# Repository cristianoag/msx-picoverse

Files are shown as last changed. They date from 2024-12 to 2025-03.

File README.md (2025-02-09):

# MSX PicoVerse - The MSX experience driven by the RaspBerry Pi Pico

The MSX PicoVerse is an open-source initiative aimed at developing multi-function cartridges for the MSX line of computers, utilizing variations of the Raspberry Pi Pico development boards with the RP2040 and RP2350 integrated chips. 

This project aspires to enhance the MSX experience by enabling users to load ROMs, emulate hardware, connect to wireless networks, or even create new hardware through a software-defined approach.

The project is still in development, and we are looking for contributors to help us develop the hardware and software. If you are interested in contributing, please reach out.

> **Note:** At this moment there is no guarantee that the boards and or software will work as expected. This project is still a work in progress. If you decide to build the hardware, you do so at your own risk.

## Hardware

Hardware was designed in two classes, first covering the RP2040 chip variants and the second covering the RP2350B chip variants. The designs are based on the Raspberry Pico development boards, which are widely available and have a large community of developers.

### Cartridges based on the RP2040 chip (PicoVerse 2040)

The RP2040 is a dual-core ARM Cortex-M0+ microcontroller operating initially at 133 MHz, featuring 264 KB of SRAM and support for external flash memory. It offers a variety of interfaces, including GPIO pins, SPI, I²C, UART, ADCs, PWM channels, and USB support.

| Prototype PCB (front) | Prototype PCB (back) |
|---|---|
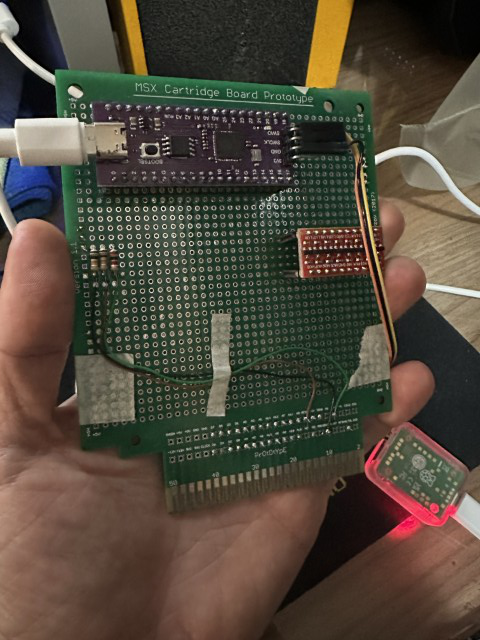
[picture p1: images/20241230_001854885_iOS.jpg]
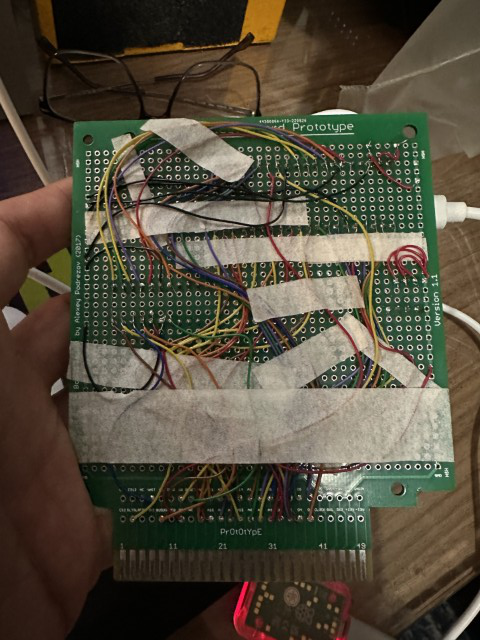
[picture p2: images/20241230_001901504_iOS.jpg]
|  |  | 

PicoVerse 2040 cartridges are designed for development boards that expose 30 GPIO pins and are **NOT compatible** with standard Raspberry Pi Pico boards. 

The goal was to use only the GPIO pins available on the boards and avoid the use of IO pin expanders or other components that could increase the complexity of the design. 

#### PicoVerse 2040 MultiRom Cartridge

The PicoVerse 2040 MultiRom allows usets to load multiple ROMs into the cartridge and select which one to boot the MSX. The cartridge has a USB port that can be used to connect it to a PC with Windows or Linux and transfer the ROMs to the Pico flash memory.

A few boards were designed for the PicoVerse 2040 MultiRom Cartridge. Most of them have the GPIO pins connected to the MSX bus through level shifters. The level shifters are used to convert the 3.3V signals from the Pico board to 5V signals that are used by the MSX bus. 

One of the boards was designed to have the majority of the GPIO pins connected directly to the MSX bus without level shifters. There is a debate about the safety of connecting the Pico GPIOs directly to 5V, as it can damage the board as it is not officially documented that the GPIO pins can be connected directly to 5V. So use the board with the level shifters if you are concerned about that. 

The boards highlighted below have the same features, the only difference is the presence of level shifters in the first one. They both use the Purple RP2040 board that is available on AliExpress and exposes 30 GPIOs.

|Cartridge Design Files|BOM|Image|
|---|---|---|
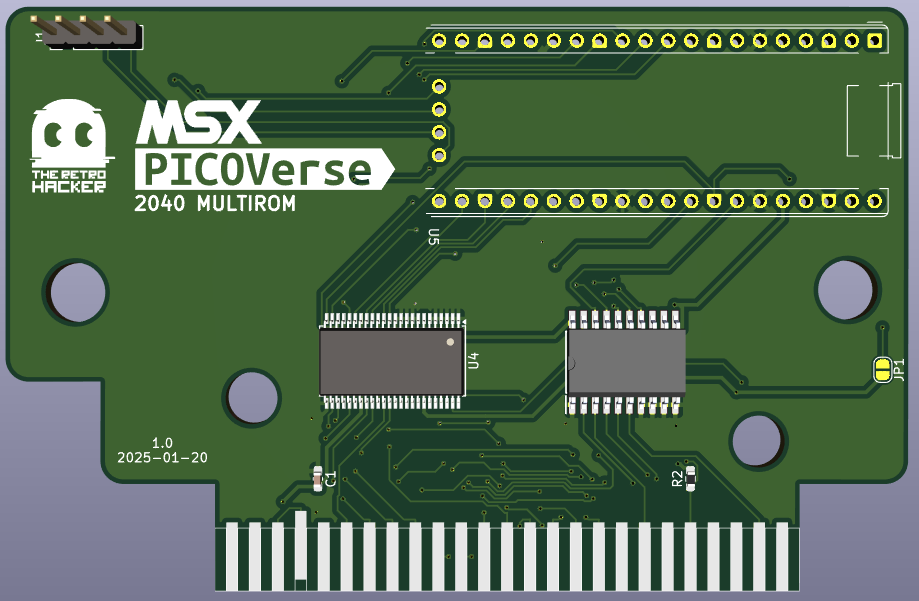
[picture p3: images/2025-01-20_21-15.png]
|[PicoVerse 2040 MultiRom](multirom/hardware/ALIEXPRESS-RP2040-PURPLE/1.0)|[BOM](https://htmlpreview.github.io/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)||
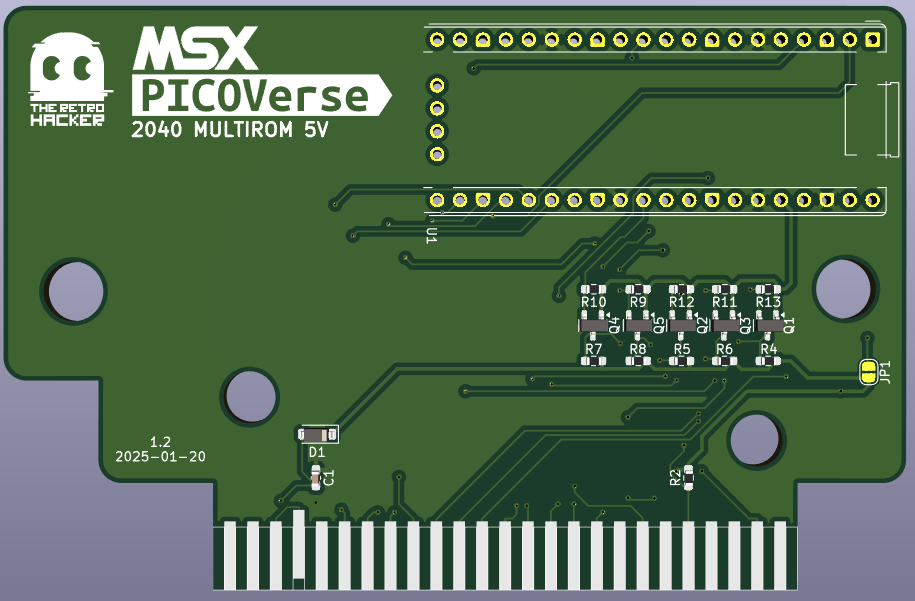
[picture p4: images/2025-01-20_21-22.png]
|[PicoVerse 2040 MultiRom 5V](multirom/hardware/ALIEXPRESS-RP2040-PURPLE-5V/1.2)|[BOM](https://htmlpreview.github.io/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)||

#### PicoVerse 2040 Audio Cartridge

The PicoVerse 2040 Audio Cartridge is a cartridge that allows the user to play MP3 audio files on the MSX computer and implements audio related resources to be used by software running on the MSX computer. The cartridge has a USB port that can be used to connect the cartridge to a computer and transfer simple (up to 48KB) ROMs or music files to the Pico flash memory. 

At this moment the cartridge features a MP3 player client for the MSX computer that can be used to play music files stored on the Pico flash memory.

|Cartridge Design Files|BOM|Image|
|---|---|---|
|TBI|||

#### PicoVerse 2040 WiFi Cartridge

The PicoVerse 2040 WiFi Cartridge is a cartridge that allows the user to connect the MSX computer to a wireless network. The cartridge has a USB port that can be used to connect the cartridge to a computer and update the firmware.

The cartridge features a UNAPI driver for the MSX computer that can be used to connect to a wireless network. The driver was created by Oduvaldo Pavan Jr. and is available on his [GitHub repository](https://github.com/ducasp/MSX-Development).

|Cartridge Design Files|BOM|Image|
|---|---|---|
|TBI|||

### Cartridges based on the RP2350B chip (PicoVerse 2350)

The RP2350, introduced in August 2024 by Raspberry Pi Ltd., is a high-performance microcontroller featuring a dual-core, dual-architecture design with selectable Arm Cortex-M33 or Hazard3 RISC-V cores, operating up to 150 MHz. It includes 520 KB of on-chip SRAM, supports up to 16 MB of external QSPI flash or PSRAM, and offers multiple communication interfaces (2× UART, 2× SPI, 2× I²C), 24 PWM channels, up to 8 ADC channels, 48 GPIO pins, USB 1.1 support, and 12 PIO state machines for flexible interfacing.

| Prototype PCB (front) | Prototype PCB (back) |
|---|---|
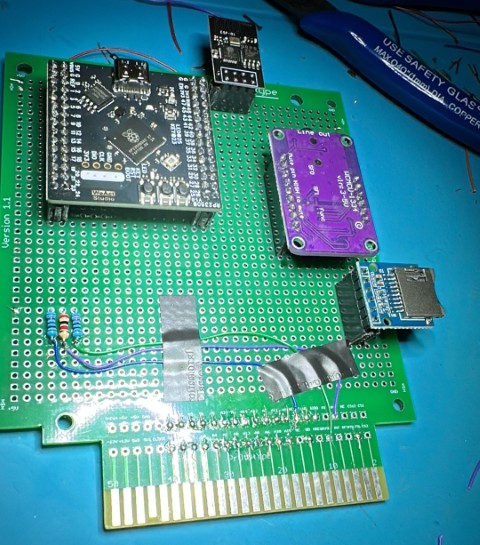
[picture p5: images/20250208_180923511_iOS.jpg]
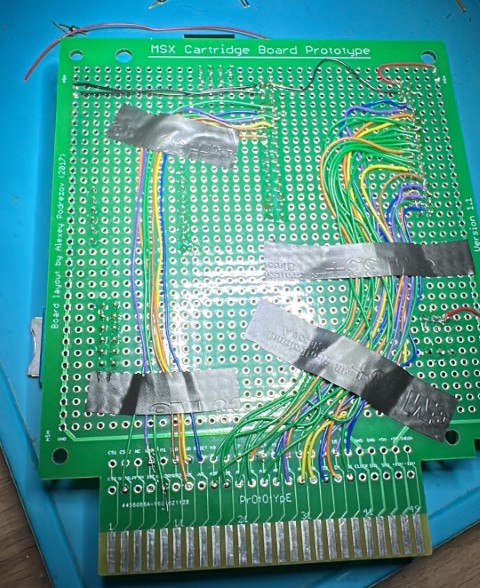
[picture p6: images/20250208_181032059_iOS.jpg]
|  |  |

PicoVerse 2350 cartridges are based on development boards that expose 48 GPIO pins and are **NOT compatible** with conventional Raspberry Pi Pico 2 development boards, which typically expose only 26 GPIO pins. 

#### PicoVerse 2350 Multirom Cartridge

This is a combined cartridge that includes the features of the PicoVerse 2040 MultiRom, Audio, and WiFi cartridges. The cartridge has a USB port that can be used to connect the cartridge to a computer and transfer ROM or music files to the Pico flash memory.

|Cartridge Design Files|BOM|Image|
|---|---|---|
|TBI|||

## Software

The software for the PicoVerse cartridges is being developed and it will be fully open-sourced. 

The RP2040 based carts are also compatible with the [MSX&#960;](https://github.com/piigaa-densetu-two-dai/MSXpi) project created by @piigaa-densetu-two-dai, so you can use any of the software alternatives created for that board with this open source hardware.

#### PicoVerse 2040 MultiRom Cartridge

As this was the first cartridge to be developed, there are a few software options available. You can check options with descriptions and download links in the [software](2040/multirom/software) folder.

The PicoVerse 2040 MultiRom Cartridge is also compatible with the [MSX&#960;](https://github.com/piigaa-densetu-two-dai/MSXpi) project created by @piigaa-densetu-two-dai, so you can use any of the software alternatives created for that board with this open source hardware.

#### PicoVerse 2040 Audio Cartridge

The software for the PicoVerse 2040 Audio Cartridge is being developed. The software will be fully open-sourced.

#### PicoVerse 2040 WiFi Cartridge

The software for the PicoVerse 2040 WiFi Cartridge is being developed. The software will be fully open-sourced.

#### PicoVerse 2350 Multirom Cartridge

The software for the PicoVerse 2350 Multirom Cartridge is being developed. You can check options with descriptions and download links in the [software](2350/multirom/software) folder.

## License 

Open Hardware

This work is licensed under a [Creative Commons Attribution-NonCommercial-ShareAlike 4.0 International License](http://creativecommons.org/licenses/by-nc-sa/4.0/).

* If you remix, transform, or build upon the material, you must distribute your contributions under the same license as the original.
* You may not use the material for commercial purposes.
* You must give appropriate credit, provide a link to the license, and indicate if changes were made. You may do so in any reasonable manner, but not in any way that suggests the licensor endorses you or your use.

**ATTENTION**

This project was made for the retro community and not for commercial purposes. So only retro hardware forums and individual people can build this project.

THE SALE OF ANY PART OF THIS PROJECT WITHOUT EXPRESS AUTHORIZATION IS PROHIBITED!

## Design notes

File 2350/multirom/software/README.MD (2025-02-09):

# MSX PICOVERSE 2350 MULTIROM SOFTWARE PLAYGROUND

This page summarizes the software options currently available or in development for the PicoVerse 2350 MultiRom cartridge. 

## Software and Tools you may need to develop for the PicoVerse 2350

* [Visual Studio Code]( https://code.visualstudio.com/) - Code editor that can be used to develop software for the PicoVerse 2040 cartridges.
* [Raspberry Pi Pico SDK](https://github.com/raspberrypi/pico-sdk) - The SDK is a collection of libraries and tools that are designed to make it easy to write programs for the RP2040 microcontroller.  
* [SDCC](http://sdcc.sourceforge.net/) - Small Device C Compiler. Standard C (ANSI C89, ISO C99, ISO C11) compiler that targets the Zilog Z80 based microcontrollers (z80, z180, gbz80, Rabbit 2000/3000, Rabbit 3000A, TLCS-90) for cross-development on Windows, macOS, and Linux. 
* [Fusion-C v1.3](https://github.com/ericb59/FUSION-C-1.3) - Fusion-C is a set of development tools for the MSX system that allows you to write MSX software in C language.
* [MYSYS2](https://www.msys2.org/) - A collection of GNU utilities and open-source software that provides functionality similar to a Linux distribution on Windows. If you are using Windows to develop for the cartridge.
* [GNU Make](https://www.gnu.org/software/make/) - A tool that controls the generation of executables and other non-source files of a program from the program's source files.
* [uf2conv.exe](https://github.com/microsoft/uf2/) - Converts a binary file to a UF2 file. This is used to convert resultant binary files to a UF2 file that can be flashed to the PICO board. 

## Software

### [loadrom](loadrom/)

This is a firmware to load a single ROM image (up to 10MB) from the flash memory of the PICO 2350 board. The ROM image is read directly from the flash memory and then executed. At this moment the tool can load and execute ROMs of the following types:

* Plain16  
* Plain32  
* Linear0  
* Konami SCC  
* Konami (without SCC)  
* ASCII8  
* ASCII16 
* NEO-8 
* NEO-16

To use you need to run loadrom.exe passing the ROM file as a parameter. The tool will read the ROM file, detect the mapper used using a heuristic approach, and then create a UF2 file that can be used to program the PICO board. 
```
loadrom.exe romfile.rom
```
After the tool execution, you need to connect your cartridge to the PC via the USB-C cable with the BOOTSEL button pushed, and copy the loadrom.uf2 file to drive that will be created in your operating system. The ROM will be loaded and executed on the MSX when the cartridge is inserted to the slot.

### [multirom](multirom/)

This is an alternative firmware that allows the selection of a ROM image from a list of ROMs stored in the flash memory of the PICO 2350 board. The ROM image is read directly from the Raspberry Pi Pico flash memory and executed on the MSX. 

At this moment the tool can load and execute following ROM types:

* Plain16  
* Plain32  
* Linear0  
* Konami SCC  
* Konami (without SCC)  
* ASCII8  
* ASCII16  
* NEO-8 
* NEO-16
  
To use it you need to run the multirom.exe tool in the same folder as the ROM files. Please rename the ROM files with names with up to 20 characters in the way you want them to appear in the menu. The tool will read the ROM files, detect their type and create a UF2 file that can be used to program the PICO board. 

```
multirom.exe
```
Then connect your cartridge to the PC via the USB-C cable and copy the multirom.uf2 file to the PICO board. The menu will be executed and you can select the ROM to be loaded to the MSX.

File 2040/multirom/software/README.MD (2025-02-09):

# MSX PICOVERSE 2040 MULTIROM SOFTWARE PLAYGROUND

This page summarizes the software options currently available or in development for the PicoVerse 2040 MultiRom cartridge. 

## Software and Tools you may need to develop for the PicoVerse 2040

* [Visual Studio Code]( https://code.visualstudio.com/) - Code editor that can be used to develop software for the PicoVerse 2040 cartridges.
* [Raspberry Pi Pico SDK](https://github.com/raspberrypi/pico-sdk) - The SDK is a collection of libraries and tools that are designed to make it easy to write programs for the RP2040 microcontroller.  
* [SDCC](http://sdcc.sourceforge.net/) - Small Device C Compiler. Standard C (ANSI C89, ISO C99, ISO C11) compiler that targets the Zilog Z80 based microcontrollers (z80, z180, gbz80, Rabbit 2000/3000, Rabbit 3000A, TLCS-90) for cross-development on Windows, macOS, and Linux. 
* [Fusion-C v1.3](https://github.com/ericb59/FUSION-C-1.3) - Fusion-C is a set of development tools for the MSX system that allows you to write MSX software in C language.
* [MYSYS2](https://www.msys2.org/) - A collection of GNU utilities and open-source software that provides functionality similar to a Linux distribution on Windows. If you are using Windows to develop for the cartridge.
* [GNU Make](https://www.gnu.org/software/make/) - A tool that controls the generation of executables and other non-source files of a program from the program's source files.
* [uf2conv.exe](https://github.com/microsoft/uf2/) - Converts a binary file to a UF2 file. This is used to convert resultant binary files to a UF2 file that can be flashed to the PICO board. 

## Software

### [testflash1](testflash1/)

This is small test program that demonstrates how to read the content of a ROM image that is appended to the end of the main program in the PICO flash memory. The ROM data is read from the flash memory and dumped to the serial console in hexdump format.

To use it you need to concatenate the ROM to the resultant bin file for the testflash1. Use the following commands to prepare the UF2 file:

```
copy /b testflash1.bin+romfile.rom testflash1-rom.bin
uf2conv.exe testflash1-rom.bin testflash1-rom.uf2
```

### [loadrom](loadrom/dist/)

This is a firmware to load a single ROM image (up to 10MB) from the flash memory of the PICO board. The ROM image is read directly from the flash memory and then executed. At this moment the tool can load and execute ROMs of the following types:

* Plain16  
* Plain32  
* Linear0  
* Konami SCC  
* Konami (without SCC)  
* ASCII8  
* ASCII16 
* NEO-8 
* NEO-16

To use you need to run loadrom.exe passing the ROM file as a parameter. The tool will read the ROM file, detect the mapper used using a heuristic approach, and then create a UF2 file that can be used to program the PICO board. 
```
loadrom.exe romfile.rom
```
After the tool execution, you need to connect your cartridge to the PC via the USB-C cable with the BOOTSEL button pushed, and copy the loadrom.uf2 file to drive that will be created in your operating system. The ROM will be loaded and executed on the MSX when the cartridge is inserted to the slot.

### [multirom](multirom/)

This is an alternative firmware that allows the selection of a ROM image from a list of ROMs stored in the flash memory of the PICO board. The ROM image is read directly from the Raspberry Pi Pico flash memory and executed on the MSX. 

|Menu - Page1|Menu - Page2|
|---|---|
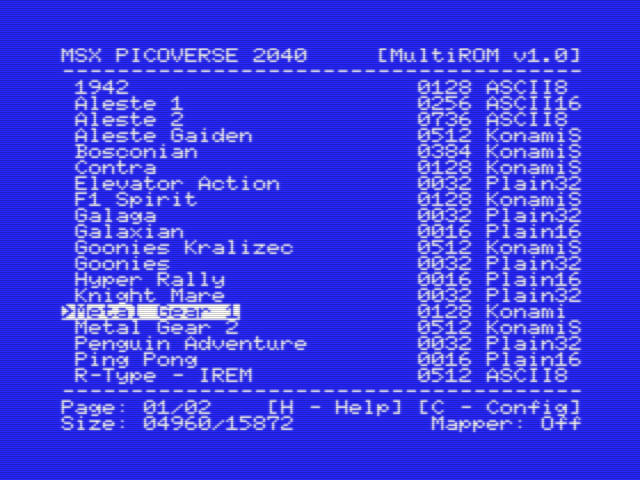
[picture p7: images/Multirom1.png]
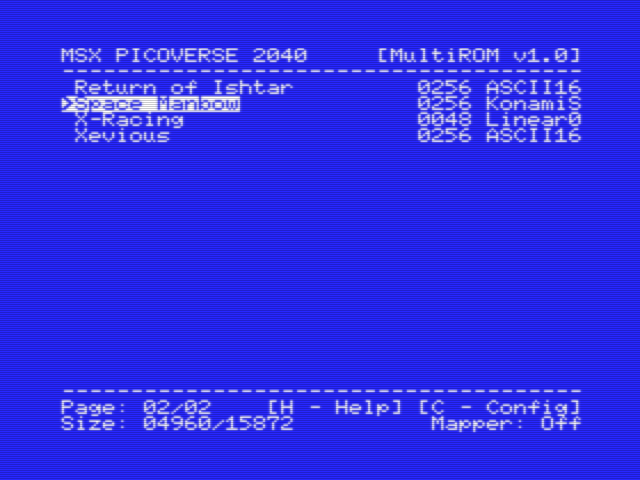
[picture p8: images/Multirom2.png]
|||

At this moment the tool can load and execute following ROM types:

* Plain16  
* Plain32  
* Linear0  
* Konami SCC  
* Konami (without SCC)  
* ASCII8  
* ASCII16  
* NEO-8 
* NEO-16
  
To use it you need to run the multirom.exe tool in the same folder as the ROM files. Please rename the ROM files with names with up to 20 characters in the way you want them to appear in the menu. The tool will read the ROM files, detect their type and create a UF2 file that can be used to program the PICO board. 

```
multirom.exe
```
Then connect your cartridge to the PC via the USB-C cable and copy the multirom.uf2 file to the PICO board. The menu will be executed and you can select the ROM to be loaded to the MSX.

### [mmapper](mmapper/)

The mmapper firmwate implements a 128KB memory mapper on the MSX computer. You just need to compile the code and copy the UF2 file to the PICO board. The firmware will be loaded and the memory mapper will be available to the MSX computer.

### [flashrom](flashrom/)

The Flashrom firmware allows loading ROMs from the Raspberry Pi Pico's flash memory. When you flash the cartridge with this firmware, a new drive will be created/appear on your PC when you connect the cartridge/pico to it via USB cable. The drive has the name PICOVERSE.

You can then push and hold the BOOTSEL button on the cartridge to format the drive and then drag and drop ROM files to it. The cartridge will then read the ROM files and make them available to the MSX computer user via a menu system. The user can then select the ROM to be loaded into the MSX computer.

* FatFS - http://elm-chan.org/fsw/ff/
* PicoUSB Flash Drive - https://github.com/oyama/pico-usb-flash-drive
* SPIFTL - Embedded, Static Wear-Leveling FTL Library - https://github.com/earlephilhower/SPIFTL

```
In development
```

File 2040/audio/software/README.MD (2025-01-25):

# MSX PICOVERSE 2040 AUDIO SOFTWARE PLAYGROUND

This page summarizes the software options currently available or in development for the PicoVerse 2040 Audio cartridge. 

## Software and Tools you may need to develop for the PicoVerse 2040

* [Visual Studio Code]( https://code.visualstudio.com/) - Code editor that can be used to develop software for the PicoVerse 2040 cartridges.
* [Raspberry Pi Pico SDK](https://github.com/raspberrypi/pico-sdk) - The SDK is a collection of libraries and tools that are designed to make it easy to write programs for the RP2040 microcontroller.  
* [SDCC](http://sdcc.sourceforge.net/) - Small Device C Compiler. Standard C (ANSI C89, ISO C99, ISO C11) compiler that targets the Zilog Z80 based microcontrollers (z80, z180, gbz80, Rabbit 2000/3000, Rabbit 3000A, TLCS-90) for cross-development on Windows, macOS, and Linux. 
* [Fusion-C v1.3](https://github.com/ericb59/FUSION-C-1.3) - Fusion-C is a set of development tools for the MSX system that allows you to write MSX software in C language.
* [MYSYS2](https://www.msys2.org/) - A collection of GNU utilities and open-source software that provides functionality similar to a Linux distribution on Windows. If you are using Windows to develop for the cartridge.
* [GNU Make](https://www.gnu.org/software/make/) - A tool that controls the generation of executables and other non-source files of a program from the program's source files.
* [uf2conv.exe](https://github.com/microsoft/uf2/) - Converts a binary file to a UF2 file. This is used to convert resultant binary files to a UF2 file that can be flashed to the PICO board. 

## Software

### [loadmp3](loadmp3/)

Loadmp3 is a simple utility that converts MP3 files to a format that can be played by the PicoVerse 2040 Audio cartridge. The utility converts MP3 files to a format that can be played by the UDA1334A I2S Stereo DAC. 

```
loadmp3 <filename>
```
After the tool execution, you need to connect your cartridge to the PC via the USB-C cable with the BOOTSEL button pushed, and copy the loadrom.uf2 file to drive that will be created in your operating system. The MP3 file will be played on your MSX computer. 

### [musicplayer](musicplayer/)

This is a simple music player that plays music files stored in the flash memory of the PICO board. The music files are stored in the flash memory and are played using the UDA1334A I2S Stereo DAC. The music player supports the following file formats:

* MP3

In development!

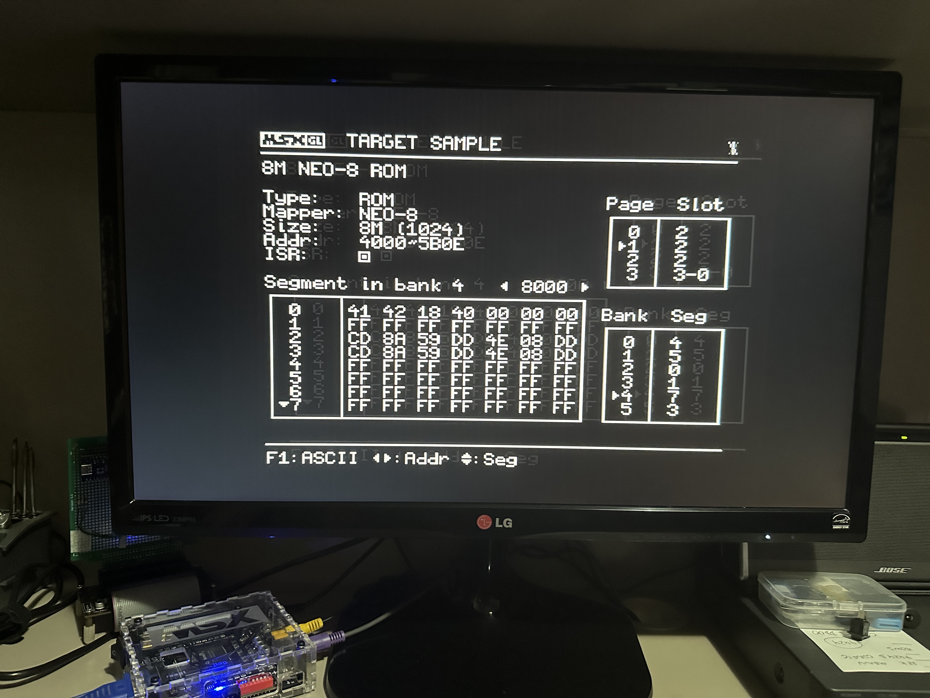
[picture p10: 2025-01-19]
images/20250119_003103586_iOS.jpg

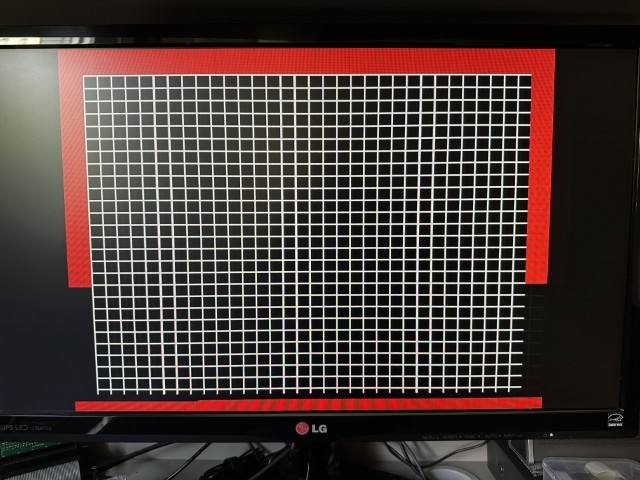
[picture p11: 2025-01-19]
images/20250119_131752036_iOS.jpg

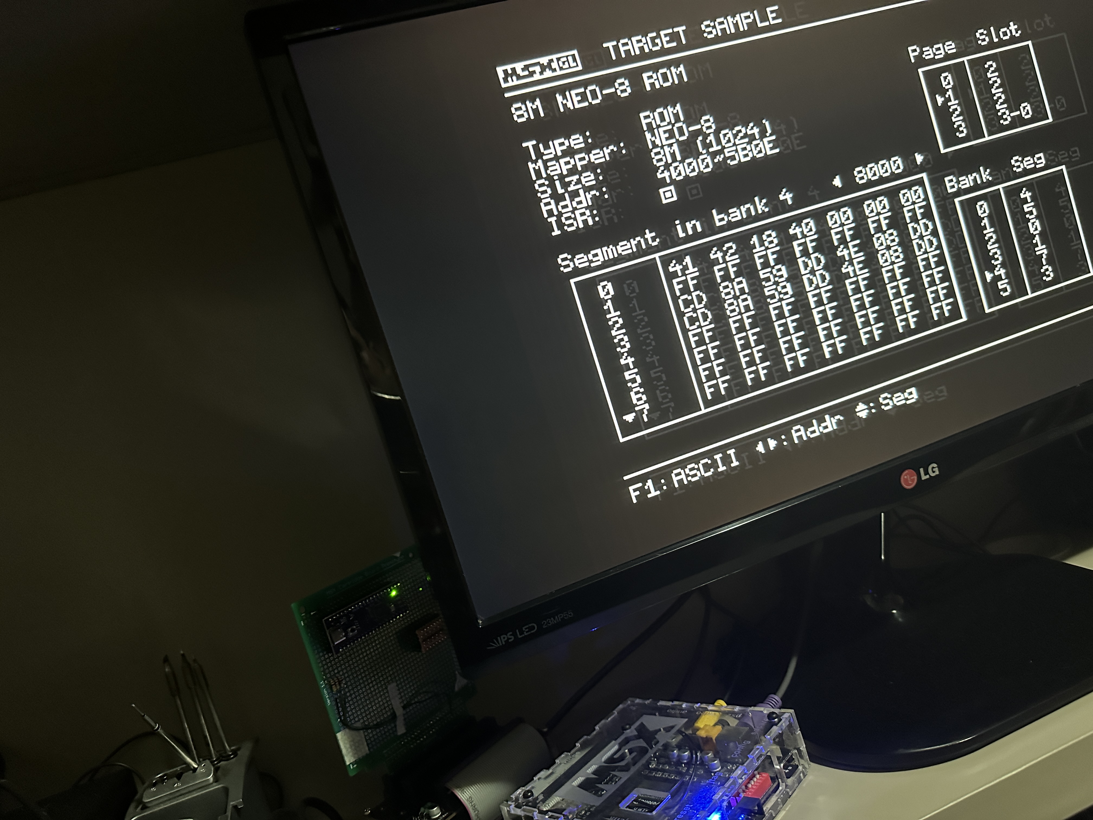
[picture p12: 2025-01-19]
images/20250119_003108009_iOS.jpg

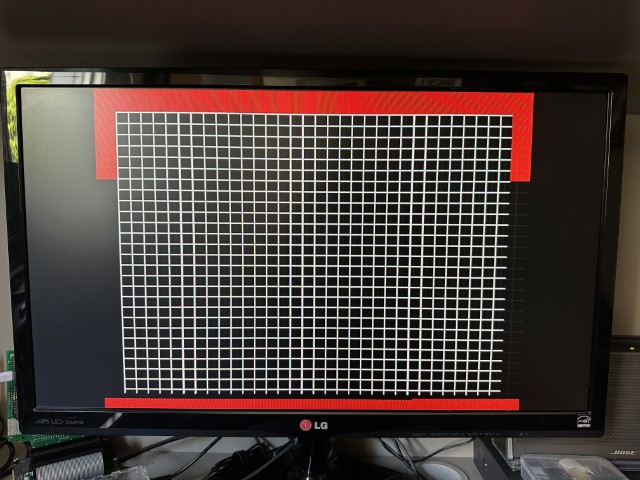
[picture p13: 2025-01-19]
images/20250119_131814592_iOS.jpg

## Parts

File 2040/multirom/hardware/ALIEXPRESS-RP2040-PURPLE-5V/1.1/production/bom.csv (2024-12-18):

Designator | Footprint | Quantity | Value | LCSC Part #
C1 | 0603 | 1 | 0.1uF
C2 | 0603 | 1 | 10uF
D1 | D_SOD-123 | 1 | 1N5819
EDG1 | msx-con-MSXCART | 1 | MSX_CON
JP1 | SolderJumper-2_P1.3mm_Open_RoundedPad1.0x1.5mm | 1 | Jumper_2_Open
Q1, Q2, Q3, Q4, Q5 | SOT-23 | 5 | BSS138
R1 | 0603 | 1 | 2K
R10, R11, R12, R13, R2, R3, R4, R5, R6, R7, R8, R9 | 0603 | 12 | 10K
U1 | RP2040-PURPLE | 1 | RP2040-PURPLE

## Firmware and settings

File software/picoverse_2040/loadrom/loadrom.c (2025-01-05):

// MSX PICOVERSE PROJECT
// (c) 2024 Cristiano Goncalves
// The Retro Hacker
//
// loadrom.c - Simple ROM loader for MSX PICOVERSE project - v1.0
//
// This is  small test program that demonstrates how to load simple ROM images using the MSX PICOVERSE project. 
// You need to concatenate the ROM image to the  end of this program binary in order  to load it.
// The program will then act as a simple ROM cartridge that responds to memory read requests from the MSX.
// 
// This work is licensed  under a "Creative Commons Attribution-NonCommercial-ShareAlike 4.0 International
// License". https://creativecommons.org/licenses/by-nc-sa/4.0/

#include <stdio.h>
#include <string.h>
#include "pico/stdlib.h"
#include "hardware/clocks.h"

#define MAX_MEM_SIZE (64*1024) // Maximum memory size
#define MAX_ROM_SIZE (48*1024) // Maximum ROM Size

// -----------------------
// User-defined pin assignments for the Raspberry Pi Pico
// -----------------------
// Address lines (A0-A15) as inputs from MSX
#define PIN_A0     0 
#define PIN_A1     1
#define PIN_A2     2
#define PIN_A3     3
#define PIN_A4     4
#define PIN_A5     5
#define PIN_A6     6
#define PIN_A7     7
#define PIN_A8     8
#define PIN_A9     9
#define PIN_A10    10
#define PIN_A11    11
#define PIN_A12    12
#define PIN_A13    13
#define PIN_A14    14
#define PIN_A15    15

// Data lines (D0-D7)
#define PIN_D0     16
#define PIN_D1     17
#define PIN_D2     18
#define PIN_D3     19
#define PIN_D4     20
#define PIN_D5     21
#define PIN_D6     22
#define PIN_D7     23

// Control signals
#define PIN_RD     24   // Read strobe from MSX
#define PIN_WR     25   // Write strobe from MSX
#define PIN_IORQ   26   // IO Request line from MSX
#define PIN_SLTSL  27   // Slot Select for this cartridge slot
#define PIN_WAIT    28  // WAIT line to MSX 
#define PIN_BUSSDIR 29  // Bus direction line 

// This symbol marks the end of the main program in flash.
// The ROM data is concatenated immediately after this point.
extern unsigned char __flash_binary_end;

// Optionally copy the ROM into this SRAM buffer for faster access
static uint8_t rom_sram[MAX_MEM_SIZE];
static bool USE_SRAM_COPY = true;
// The ROM is concatenated right after the main program binary.
// __flash_binary_end points to the end of the program in flash memory.
const uint8_t *rom = (const uint8_t *)&__flash_binary_end;

// Struct to hold both address and data
typedef struct {
    uint16_t address;
    uint8_t data;
} bus_data_t;

// Read the address bus from the MSX
static inline uint16_t read_address_bus(void) {
    // Return first 16 bits in the most efficient way
    return gpio_get_all() & 0x00FFFF;
}

// Read a byte from the data bus
static inline uint8_t read_data_bus(void) 
{
    // Read the data bus
    return (gpio_get_all() >> 16) & 0xFF;
}

// Write a byte to the data bus
static inline void write_data_bus(uint8_t data) {
    // Write the given byte to the given address
    gpio_put_masked(0xFF0000, data << 16);
}

// Read both the address and data bus
static inline bus_data_t read_address_and_data_bus(void) {
    uint32_t gpio_values = gpio_get_all();
    bus_data_t result;
    result.address = gpio_values & 0x00FFFF;  // Lower 16 bits for address
    result.data = (gpio_values >> 16) & 0xFF; // Upper 8 bits for data
    return result;
}

// Set the data bus to input mode
static inline void set_data_bus_input(void) {
    // Set data lines to input (high impedance)
    gpio_set_dir(PIN_D0, GPIO_IN);
    gpio_set_dir(PIN_D1, GPIO_IN);
    gpio_set_dir(PIN_D2, GPIO_IN);
    gpio_set_dir(PIN_D3, GPIO_IN);
    gpio_set_dir(PIN_D4, GPIO_IN);
    gpio_set_dir(PIN_D5, GPIO_IN);
    gpio_set_dir(PIN_D6, GPIO_IN);
    gpio_set_dir(PIN_D7, GPIO_IN);
}

// Set the data bus to output mode
static inline void set_data_bus_output(void)
{
    gpio_set_dir(PIN_D0, GPIO_OUT);
    gpio_set_dir(PIN_D1, GPIO_OUT);
    gpio_set_dir(PIN_D2, GPIO_OUT);
    gpio_set_dir(PIN_D3, GPIO_OUT);
    gpio_set_dir(PIN_D4, GPIO_OUT);
    gpio_set_dir(PIN_D5, GPIO_OUT);
    gpio_set_dir(PIN_D6, GPIO_OUT);
    gpio_set_dir(PIN_D7, GPIO_OUT);
}

// Initialize GPIO pins
static inline void setup_gpio()
{
    // address pins
    gpio_init(PIN_A0);  gpio_set_dir(PIN_A0, GPIO_IN);
    gpio_init(PIN_A1);  gpio_set_dir(PIN_A1, GPIO_IN);
    gpio_init(PIN_A2);  gpio_set_dir(PIN_A2, GPIO_IN);
    gpio_init(PIN_A3);  gpio_set_dir(PIN_A3, GPIO_IN);
    gpio_init(PIN_A4);  gpio_set_dir(PIN_A4, GPIO_IN);
    gpio_init(PIN_A5);  gpio_set_dir(PIN_A5, GPIO_IN);
    gpio_init(PIN_A6);  gpio_set_dir(PIN_A6, GPIO_IN);
    gpio_init(PIN_A7);  gpio_set_dir(PIN_A7, GPIO_IN);
    gpio_init(PIN_A8);  gpio_set_dir(PIN_A8, GPIO_IN);
    gpio_init(PIN_A9);  gpio_set_dir(PIN_A9, GPIO_IN);
    gpio_init(PIN_A10); gpio_set_dir(PIN_A10, GPIO_IN);
    gpio_init(PIN_A11); gpio_set_dir(PIN_A11, GPIO_IN);
    gpio_init(PIN_A12); gpio_set_dir(PIN_A12, GPIO_IN);
    gpio_init(PIN_A13); gpio_set_dir(PIN_A13, GPIO_IN);
    gpio_init(PIN_A14); gpio_set_dir(PIN_A14, GPIO_IN);
    gpio_init(PIN_A15); gpio_set_dir(PIN_A15, GPIO_IN);

    // data pins
    gpio_init(PIN_D0); 
    gpio_init(PIN_D1); 
    gpio_init(PIN_D2); 
    gpio_init(PIN_D3); 
    gpio_init(PIN_D4); 
    gpio_init(PIN_D5); 
    gpio_init(PIN_D6);  
    gpio_init(PIN_D7); 

    // Initialize control pins as input
    gpio_init(PIN_RD); gpio_set_dir(PIN_RD, GPIO_IN);
    gpio_init(PIN_WR); gpio_set_dir(PIN_WR, GPIO_IN);
    gpio_init(PIN_IORQ); gpio_set_dir(PIN_IORQ, GPIO_IN);
    gpio_init(PIN_SLTSL); gpio_set_dir(PIN_SLTSL, GPIO_IN);
    gpio_init(PIN_BUSSDIR); gpio_set_dir(PIN_BUSSDIR, GPIO_IN);
}

// Detect the ROM type by analyzing the AB signature at 0x0000 and 0x0001 or 0x4000 and 0x4001
static uint32_t detect_rom_type(const uint8_t *rom, size_t max_size) {
    // Check if the ROM has the signature "AB" at 0x0000 and 0x0001
    // Those are the cases for 16KB and 32KB ROMs
    if (rom[0] == 'A' && rom[1] == 'B') {
        return 32768;     // I can return 32768 for both
    }
    // Check if the ROM has the signature "AB" at 0x4000 and 0x4001
    // That is the case for 48KB ROMs with Linear page 0 config
    if (rom[0x4000] == 'A' && rom[0x4001] == 'B') {
        return 49152; // 48KB
    }
    return max_size; // If no signature found, assume full size
}

// Load a simple 32KB ROM into the MSX
// They have two pages of 16Kb each in the following areas:
// 0x4000-0x7FFF and 0x8000-0xBFFF
// AB is on 0x0000, 0x0001
// The ROM data is stored in the flash memory starting at __flash_binary_end
int loadrom_32k(uint32_t offset, uint32_t size)
{
    // if SRAM copy is enabled, copy the ROM data to the SRAM buffer
    if (USE_SRAM_COPY) {
       gpio_init(PIN_WAIT); gpio_set_dir(PIN_WAIT, GPIO_OUT);
       gpio_put(PIN_WAIT, 0); // Wait until we are ready to read the ROM
       //memcpy(rom_sram, rom + offset, size);
       //copy the flash content to pages 1 and 2 (0x4000-0x7FFF and 0x8000-0xBFFF)
       memcpy(rom_sram + 0x4000, rom + offset, size);
       gpio_put(PIN_WAIT, 1); // Lets go!
    }

    // Set data bus to input mode
    set_data_bus_input();
    while (true) 
    {
        // Check control signals
        bool sltsl = (gpio_get(PIN_SLTSL) == 0); // Slot select (active low)
        bool rd = (gpio_get(PIN_RD) == 0);       // Read cycle (active low)
        uint16_t addr = read_address_bus();
        if (sltsl) 
        {
            // Check if the address is within the ROM range
            if (addr >= 0x4000 && addr <= 0xBFFF) 
            {
                uint16_t flash_offset = (addr - 0x4000) + offset;
                if (rd)
                {
                    uint8_t data = USE_SRAM_COPY ? rom_sram[addr] : rom[flash_offset];
                    set_data_bus_output(); // Drive data bus to output mode
                    write_data_bus(data);  // Drive data onto the bus
                    while (gpio_get(PIN_RD) == 0)  // Wait until the read cycle completes (RD goes high)
                    {
                        tight_loop_contents();
                    }
                    set_data_bus_input(); // Return data lines to input mode after cycle completes
                }

            } 
        } 
    }
    return 0;
}

// Load a simple 48KB Linear0 ROM into the MSX
// Those ROMs have three pages of 16Kb each in the following areas:
// 0x0000-0x3FFF, 0x4000-0x7FFF and 0x8000-0xBFFF
// AB is on 0x4000, 0x4001
// The ROM data is stored in the flash memory starting at __flash_binary_end
int loadrom_48k_Linear0(uint32_t offset, uint32_t size)
{
    // if SRAM copy is enabled, copy the ROM data to the SRAM buffer
    if (USE_SRAM_COPY) {
       gpio_init(PIN_WAIT); gpio_set_dir(PIN_WAIT, GPIO_OUT);
       gpio_put(PIN_WAIT, 0); // Wait until we are ready to read the ROM
       // copy the flash content to pages 0, 1 and 2 (0x0000-0x3FFF, 0x4000-0x7FFF and 0x8000-0xBFFF)
       // for 48KB Linear0 ROMs we start at 0x0000
       memcpy(rom_sram, rom + offset, size);
       gpio_put(PIN_WAIT, 1); // Lets go!
    }

    // Set data bus to input mode
    set_data_bus_input();
    while (true) 
    {
        // Check control signals
        bool sltsl = (gpio_get(PIN_SLTSL) == 0); // Slot select (active low)
        bool rd = (gpio_get(PIN_RD) == 0);       // Read cycle (active low)
        bool wr = (gpio_get(PIN_WR) == 0);       // Write cycle (active low, not used)
        
        // MSX is requesting a memory read from this slot
        if (sltsl && rd && !wr) 
        {
            uint16_t addr = read_address_bus();
            // Check if the address is within the ROM range
            if (addr >= 0x0000 && addr <= 0xBFFF) 
            {
                // Address is within the ROM range
                uint16_t flash_offset = addr + offset;
                uint8_t data = USE_SRAM_COPY ? rom_sram[addr] : rom[flash_offset];

                // Drive data bus to output mode
                set_data_bus_output();
                // Drive data onto the bus
                write_data_bus(data);
                // Wait until the read cycle completes (RD goes high)
                while (gpio_get(PIN_RD) == 0) {
                    tight_loop_contents();
                   }
                // Return data lines to input mode after cycle completes
                set_data_bus_input();
            }
        } else {
            // Not a read cycle - ensure data bus is not driven
            set_data_bus_input();
        }
    }
    return 0;
}

// -----------------------
// Main program
// -----------------------
int main()
{
    // Set system clock to 240MHz
    set_sys_clock_khz(240000, true);
    // Initialize stdio
    stdio_init_all();
    // Initialize GPIO
    setup_gpio();

    uint32_t rom_size = detect_rom_type(rom, MAX_ROM_SIZE);

    switch (rom_size)
    {
        case 16384:
            printf("Detected 16KB ROM\n");
            loadrom_32k(0x0000, rom_size);
            break;
        case 32768: // 32KB ROM
            printf("Detected 32KB ROM\n");
            //loadrom_32k(0x0000, rom_size);
            loadrom_32k(0x0000, rom_size);
            printf("32KB ROM loaded!\n");
            break;
        case 49152: // 48KB ROM
            printf("Detected 48KB ROM\n");
            loadrom_48k_Linear0(0x0000, rom_size);
            break;
        default:
            printf("Unsupported ROM!\n");
            break;
    }

    return 0;
}

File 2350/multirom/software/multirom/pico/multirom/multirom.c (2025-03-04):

// MSX PICOVERSE PROJECT
// (c) 2025 Cristiano Goncalves
// The Retro Hacker
//
// multirom.c - This is the Raspberry Pico firmware that will be used to load ROMs into the MSX
//
// This firmware is responsible for loading the multirom menu and the ROMs selected by the user into the MSX. When flashed through the 
// multirom tool, it will be stored on the pico flash memory followed by the MSX MENU ROM (with the config) and all the ROMs processed by the 
// multirom tool. The sofware in this firmware will load the first 32KB ROM that contains the menu into the MSX and it will allow the user
// to select a ROM to be loaded into the MSX. The selected ROM will be loaded into the MSX and the MSX will be reseted to run the selected ROM.
//
// This work is licensed  under a "Creative Commons Attribution-NonCommercial-ShareAlike 4.0 International
// License". https://creativecommons.org/licenses/by-nc-sa/4.0/

#include <stdio.h>
#include <string.h>
#include "pico/stdlib.h"
#include "pico/multicore.h"
#include "hardware/clocks.h"
#include "hardware/structs/qmi.h"
#include "multirom.h"
#include "io.h"

// config area and buffer for the ROM data
#define MONITOR_ADDR    0x9D01     // Monitor ROM address - Configuration binary 0x8000+(ROM_RECORD_SIZE*MAX_ROM_RECORDS)+1 = 0x8000 +0x1D00 + 0x1 = 0x9D01
#define ROM_RECORD_SIZE 29      // Size of the ROM record in the configuration area in bytes
#define MAX_ROM_RECORDS 256     // Maximum ROM files supported 2^8=256
#define ROM_NAME_MAX    20         // Maximum size of the ROM name

// This symbol marks the end of the main program in flash.
// Custom data starts right after it
extern unsigned char __flash_binary_end;

//pointer to the custom data
const uint8_t *rom = (const uint8_t *)&__flash_binary_end;

// Structure to represent a ROM record
// The ROM record will contain the name of the ROM, the mapper code, the size of the ROM and the offset in the flash memory
// Name: ROM_NAME_MAX bytes
// Mapper: 1 byte
// Size: 4 bytes
// Offset: 4 bytes
typedef struct {
    char Name[ROM_NAME_MAX];
    unsigned char Mapper;
    unsigned long Size;
    unsigned long Offset;
} ROMRecord;

ROMRecord records[MAX_ROM_RECORDS]; // Array to store the ROM records

// Initialize GPIO pins
static inline void setup_gpio()
{

    for (int i = 0; i <= 23; i++) {
        gpio_init(i);
        gpio_set_input_hysteresis_enabled(i, true);
    }

    for (int i = 0; i <= 15; i++) {
        gpio_set_dir(i, GPIO_IN);
    }

    // Initialize control pins as input
    gpio_init(PIN_RD); gpio_set_dir(PIN_RD, GPIO_IN);    
    gpio_init(PIN_WR); gpio_set_dir(PIN_WR, GPIO_IN); 
    gpio_init(PIN_IORQ); gpio_set_dir(PIN_IORQ, GPIO_IN); 
    gpio_init(PIN_SLTSL); gpio_set_dir(PIN_SLTSL, GPIO_IN); 
    gpio_init(PIN_BUSSDIR); gpio_set_dir(PIN_BUSSDIR, GPIO_IN); 
}

// read_ulong - Read a 4-byte value from the memory area
// This function will read a 4-byte value from the memory area pointed by ptr and return the value as an unsigned long
// Parameters:
//   ptr - Pointer to the memory area to read the value from
// Returns:
//   The 4-byte value as an unsigned long 
unsigned long __no_inline_not_in_flash_func(read_ulong)(const unsigned char *ptr) {
    return (unsigned long)ptr[0] |
           ((unsigned long)ptr[1] << 8) |
           ((unsigned long)ptr[2] << 16) |
           ((unsigned long)ptr[3] << 24);
}

// isEndOfData - Check if the memory area is the end of the data
// This function will check if the memory area pointed by memory is the end of the data. The end of the data is defined by all bytes being 0xFF.
// Parameters:
//   memory - Pointer to the memory area to check
// Returns:
//   1 if the memory area is the end of the data, 0 otherwise
int __no_inline_not_in_flash_func(isEndOfData)(const unsigned char *memory) {
    for (int i = 0; i < ROM_RECORD_SIZE; i++) {
        if (memory[i] != 0xFF) {
            return 0;
        }
    }
    return 1;
}

//load the MSX Menu ROM into the MSX
int __no_inline_not_in_flash_func(loadrom_msx_menu)(uint32_t offset)
{
    static uint8_t rom_sram[32768];

    //setup the rom_sram buffer for the 32KB ROM
    gpio_init(PIN_WAIT); // Init wait signal pin
    gpio_set_dir(PIN_WAIT, GPIO_OUT); // Set the WAIT signal as output
    gpio_put(PIN_WAIT, 0); // Wait until we are ready to read the ROM
    memset(rom_sram, 0, 32768); // Clear the SRAM buffer
    memcpy(rom_sram, rom + offset, 32768); //for 32KB ROMs we start at 0x4000
    gpio_put(PIN_WAIT, 1); // Lets go!

    int record_count = 0; // Record count
    const uint8_t *record_ptr = rom + offset + 0x4000; // Pointer to the ROM records
    for (int i = 0; i < MAX_ROM_RECORDS; i++)      // Read the ROMs from the configuration area
    {
        if (isEndOfData(record_ptr)) {
            break; // Stop if end of data is reached
        }
        memcpy(records[record_count].Name, record_ptr, ROM_NAME_MAX); // Copy the ROM name
        record_ptr += ROM_NAME_MAX; // Move the pointer to the next field
        records[record_count].Mapper = *record_ptr++; // Read the mapper code
        records[record_count].Size = read_ulong(record_ptr); // Read the ROM size
        record_ptr += sizeof(unsigned long); // Move the pointer to the next field
        records[record_count].Offset = read_ulong(record_ptr); // Read the ROM offset
        record_ptr += sizeof(unsigned long); // Move the pointer to the next record
        record_count++; // Increment the record count
    }

    uint8_t rom_index = 0;
    gpio_set_dir_in_masked(0xFF << 16); // Set data bus to input mode
    bool rom_selected = false; // ROM selected flag
    while (true)  // Loop until a ROM is selected
    {
        // Check control signals
        bool sltsl = !(gpio_get(PIN_SLTSL)); // Slot selected (active low)
        bool rd = !(gpio_get(PIN_RD));       // Read cycle (active low)

        uint16_t addr = gpio_get_all() & 0x00FFFF; // Read the address bus
        //uint16_t addr = sio_hw->gpio_in & 0x00FFFF;
        if (sltsl) 
        {
            bool wr = !(gpio_get(PIN_WR));       // Write cycle (active low, not used)

            if (wr && addr == 0x9D01) // Monitor ROM address 0x9D01
            {   
                    rom_index = (gpio_get_all() >> 16) & 0xFF;
                    while (!(gpio_get(PIN_WR))) { // Wait until the write cycle completes (WR goes high){
                        tight_loop_contents();
                    }
                    gpio_set_dir_in_masked(0xFF << 16); // Set data bus to input mode
                    rom_selected = true;    // ROM selected
            }
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

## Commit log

2024-12-05 initial load
    [msx-picoverse.kicad_sch]
2024-12-10 ALIEXPRESS RP2040 PURPLE RP2040
    [msx-picoverse.kicad_sch]
2024-12-10 RP2040-PURPLE 5V update
    [msx-picoverse.kicad_sch]
2024-12-14 Schottky diode to prevent the pico powering the MSX
    [msx-picoverse.kicad_sch]
2024-12-18 2040 Purple 5V 1.1 and adjustments to README
    [bom.csv, designators.csv, msx-picoverse.kicad_sch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]
2024-12-30 multirom tool and pico firmware WIP
2025-01-05 License update and small fixes on the multirom tool
    [multirom.c]
2025-01-14 Olimesd launched the RP2350B boards
2025-01-15 PCB 3V3-5V conversion fix
    [bom.csv, designators.csv, msx-picoverse.kicad_sch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]
2025-01-15 iBOM for the 1.2 board
2025-01-15 mmapper and multirom with memory mapper. still issues with multirom conflicts, code commented.
    [mmapper.c, multirom.c]
2025-01-21 refactoring repo to accomodate RP2350 and options for RP2040 boards
    [bom.csv, designators.csv, msx-picoverse.kicad_sch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]
2025-01-25 loadmp3 pico code and tool
2025-02-04 Fix for plain roms below 32K and above 16K
    [loadrom.c, multirom.c]
2025-02-04 minor fix ASCII-16 mapper
    [multirom.c]
2025-02-07 weact rp2350b board wip
    [msx-picoverse.kicad_pcb, msx-picoverse.kicad_sch]
2025-02-09 2350 wip
    [msx-picoverse.kicad_pcb, msx-picoverse.kicad_sch]
2025-02-09 images of the 2350 prototype
2025-02-09 loadrom and multirom ported to 2350
    [msx-picoverse.kicad_sch]
2025-02-11 Nextor driver
2025-02-11 connecting the microSD card
    [msx-picoverse.kicad_sch]
2025-02-15 playing with SPI libraries to write blocks to the microSD
2025-02-15 playing with SPI libraries
    [msx-picoverse.kicad_sch]
2025-02-16 nextor driver wip
2025-02-16 tests with SPI and Fabio's driver
2025-02-22 nextor driver implementation
2025-02-25 Nextor driver in C. Waaaay easier.
2025-03-02 tests with PIO and DMA with the 2350B board
2025-03-03 playing with PIO + DMA
2025-03-03 pio + dma tests
2025-03-04 Nextor driver writing
